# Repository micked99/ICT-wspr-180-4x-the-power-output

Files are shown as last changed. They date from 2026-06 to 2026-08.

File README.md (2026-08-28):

Utilize the clock inverter of the Si5351 and tx the signal 180 deg out of phase on the two dipole halfs increasing the power output in theory up to 4 times, in real life we will likley see a 3x increase.

Quick messure of powerdemands - about 32mA at tx at test freq wspr 21Mhz into a dipole

PCB have been altered and the clk1 have been routed to the pcb

My original ict fw works on this pcb as only difference is the extra clk line

All setup is same as this: https://github.com/micked99/ICT-Wspr-complete-setup

This is V2 of the 180° pcb, tested and working

180deg-pcb

pcbs

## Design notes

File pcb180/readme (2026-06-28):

Files to order the pcb including .brd file and the cam files in the .zip

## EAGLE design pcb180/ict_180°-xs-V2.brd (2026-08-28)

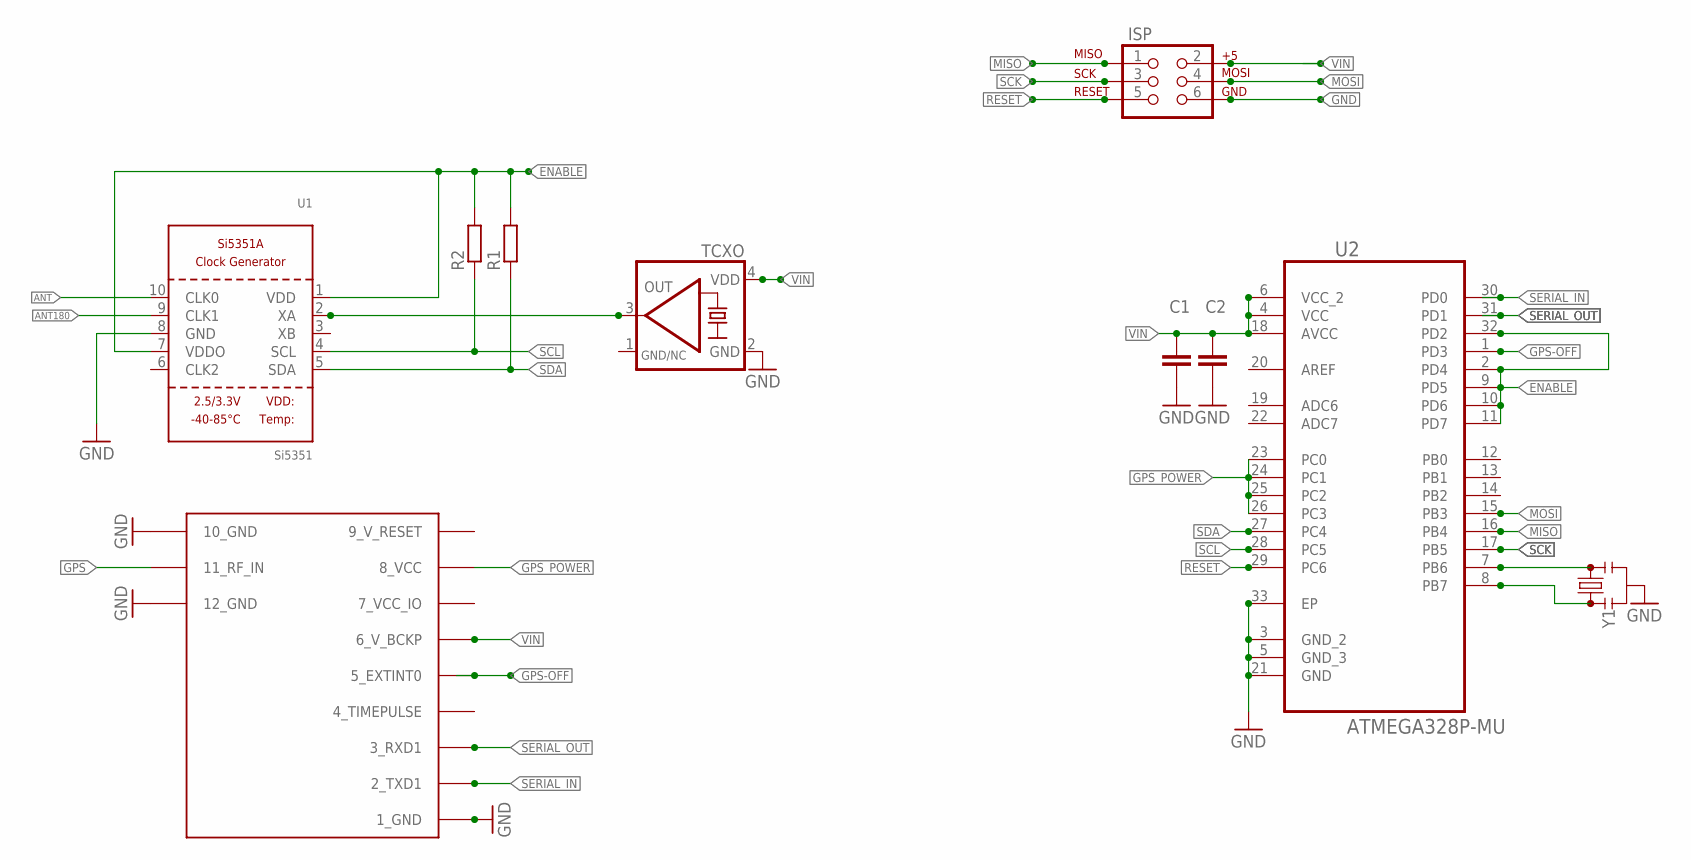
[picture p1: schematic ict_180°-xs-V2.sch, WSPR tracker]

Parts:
C1, C2: C-EUC0603K; C0603K
GPS: UBLOX_MAX
ISP: AVR_SPI_PRG_6PTH; 2X3
R1, R2: R-EU_R0603; R0603
TCXO: KXO-TCXO-CMOS-84; 3.2X2.5_KXO-84-TCXO
U1: Si5351; MSOP10
U2: ATMEGA328P-MU; QFN50P500X500X100-33N
Y1: RESONATORSMD-4.5X2.0; RESONATOR-SMD-4.5X2.0

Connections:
7_VCC_IO: GPS.7_VCC_IO
9_V_RESET: GPS.9_V_RESET
ANT: U1.10 (CLK0)
ANT180: U1.9 (CLK1)
ENABLE: R1.2, R2.2, U1.1 (VDD), U1.7 (VDDO), U2.2 (PD4), U2.9 (PD5), U2.10 (PD6), U2.11 (PD7), U2.32 (PD2)
GND: C1.2, C2.2, GPS.1_GND, GPS.10_GND, GPS.12_GND, ISP.6, TCXO.2 (GND), U1.8 (GND), U2.3 (GND_2), U2.5 (GND_3), U2.21 (GND), U2.33 (EP), Y1.2
GND/NC: TCXO.1 (GND/NC)
GPS: GPS.11_RF_IN
GPS-OFF: GPS.5_EXTINT0, U2.1 (PD3)
GPS_POWER: GPS.8_VCC, U2.23 (PC0), U2.24 (PC1), U2.25 (PC2), U2.26 (PC3)
MISO: ISP.1, U2.16 (PB4)
MOSI: ISP.4, U2.15 (PB3)
unnamed: U2.7 (PB6), Y1.3
unnamed: U2.8 (PB7), Y1.1
unnamed: TCXO.3 (OUT), U1.2 (XA)
RESET: ISP.5, U2.29 (PC6)
SCK: ISP.3, U2.17 (PB5)
SCL: R2.1, U1.4 (SCL), U2.28 (PC5)
SDA: R1.1, U1.5 (SDA), U2.27 (PC4)
SERIAL_IN: GPS.2_TXD1, U2.30 (PD0)
SERIAL_OUT: GPS.3_RXD1, U2.31 (PD1)
VIN: C1.1, C2.1, GPS.6_V_BCKP, ISP.2, TCXO.4 (VDD), U2.4 (VCC), U2.6 (VCC_2), U2.18 (AVCC)

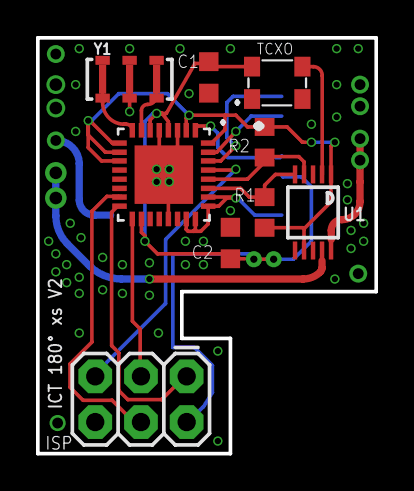
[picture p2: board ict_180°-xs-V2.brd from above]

Board: 2 copper layers, 18.8 x 23.1 mm, 10 parts (1 on the bottom side), 16 nets.

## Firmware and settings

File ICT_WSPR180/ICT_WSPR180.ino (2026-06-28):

//#pragma GCC diagnostic error "-Wconversion"

/*
   HABalloon by KD2NDR, Miami Florida October 25 2018
   Improvements by YO3ICT, Bucharest Romania, April-May 2019 
   Improvements By SA6BSS, Sweden, fall 2020
   You may use and modify the following code to suit
   your needs so long as it remains open source
   and it is for non-commercial use only.
*/

#include <avr/wdt.h>
#include <TimeLib.h>
#include <TinyGPS++.h>
#include <JTEncode.h>
#include <Wire.h>
#include <avr/pgmspace.h>
#include <avr/power.h>

//#define WSPR_FREQ     3570185UL  // <<<<< SET TX FREQUENCY HERE
//#define WSPR_FREQ     7040185UL  // <<<<< SET TX FREQUENCY HERE
//#define WSPR_FREQ     10140285UL // <<<<< SET TX FREQUENCY HERE
//#define WSPR_FREQ     14097190UL // <<<<< SET TX FREQUENCY HERE
//#define WSPR_FREQ     18106200UL  // <<<<< SET TX FREQUENCY HERE
#define WSPR_FREQ     21096190UL // <<<<< SET TX FREQUENCY HERE         
//#define WSPR_FREQ     28126235UL // <<<<< SET TX FREQUENCY HERE
#define ISM_WSPR_FREQ   13555425UL // = 1,500Hz audio on 13.553.900 Mhz // 13555425UL New correct ism freq
#define WSPR_CTC        1334       // WSPR CTC - 2668 @ 4Mhz //1334 @ 2Mhz //667 @ 1Mhz


// Enumerations
enum mode {MODE_WSPR};
TinyGPSPlus gps;
JTEncode jtencode;

// Global variables
unsigned long freq;
const char call[] = "SA7BSS";   // WSPR Standard callsign
char call_telemetry[7];         // WSPR telemetry callsign
char loc_telemetry[5];          // WSPR telemetry locator
char TestGrid[5];               // Testing grid for Geofence
uint8_t dbm, dbm_telemetry;     // Standard WSPR dbm - coarse altitude & WSPR telemetry dbm
char message_jt9[14] = "";      // JT9 Message (13 char limit)
char loc4[5];                   // 4 digit gridsquare locator
byte Hour, Minute, Second;      // Used for timing
long lat, lon, oldlat, oldlon;  // Used for location
uint8_t tx_buffer[255];         // WSPR Tx buffer
uint8_t symbol_count;           // JTencode
uint16_t tone_delay, tone_spacing, CTC; // JTencode
int alt_meters = 0;
int telemetry_set = 0;
int Sats = 0;
int gps_speed = 0;
volatile bool proceed = false;
long lastMillis = 0; 
int pwr_level=79; // Set between 76-79, to slowly increase power to ease load on the solar cells at low solar angles, 76 is really low so use from 77 and up.
int w=1;
bool Outside = true;            // Geofence flag
//GeoFence grids by Matt Downs - 2E1GYP //Airborne transmissions of this sort are not legal over North Korea and Yemen
const char NoTXGrids[] PROGMEM = {"PN31 PN41 PN20 PN30 PN40 PM29 PM39 PM28 PM38 LK16 LK15 LK14 LK13 LK23 LK24 LK25 LK26 LK36 LK35 LK34 LK33 LK44 LK45 LK46 LK47 LK48 LK58 LK57 LK56 LK55"};

#include "TelemFunctions.h"     // Various telemetry functions
#include "Beep.h"               // beeps and CW
#include "Timing-test.h"            // Scheduling, set Timing4.h for testing, it will then tx on first 2 min slot after power on, for flight set Timing.h and it will tx on the nominal 10 min scheduling

// Function Prototype
void wdt_init(void) __attribute__ ((naked, used, section(".init3")));
// Function Implementation
void wdt_init(void)
 {
  MCUSR = 0x00;  //Clear all reset flags
  WDTCSR |= (1 << WDCE) | (1 << WDE);
  WDTCSR = (1 << WDP3) | (1 << WDP0);
  return;
 }

void setup()
 {
  cli(); //Disable global interrupts
  WDTCSR |= (1 << WDCE) | (1 << WDE);
  WDTCSR = (0 << WDIE) | (1 << WDE) | (1 << WDP3) | (1 << WDP0);  // First enable the watchdog timer
  sei(); //Enable global interrupts

  clock_prescale_set(clock_div_2);
  //clock_prescale_set(clock_div_4);

  pinMode(2, OUTPUT);  // Si5351 off
  pinMode(4, OUTPUT);
  pinMode(5, OUTPUT);
  pinMode(6, OUTPUT);
  pinMode(7, OUTPUT);
  
  cw_s(); cw_a(); cw_6(); cw_b(); cw_s(); cw_s(); // Set callsign of the CW id at startup
  
  delay(80);
  pinMode(A0, OUTPUT); // GPS VCC on
  pinMode(A1, OUTPUT);
  pinMode(A2, OUTPUT);
  pinMode(A3, OUTPUT);
  digitalWrite(A0, HIGH);
  digitalWrite(A1, HIGH);
  digitalWrite(A2, HIGH);
  digitalWrite(A3, HIGH);
  delay(1500);
  Serial.begin(9600);

  //delay(2500); Serial.write("$PMTK886,3*2B\r\n");   //set balloon mode for QUECTEL L70 GPS module
  delay(2500); Serial.write("$PCAS04,1*18\r\n");      //GPS only ATGM336
  //delay(2500); Serial.write("$PCAS04,2*1B\r\n");    //BD  only ATGM336
  //delay(2500); Serial.write("$PCAS04,7*1E\r\n");    //All ATGM336 
  //delay(2500); Serial.print("$PSIMNAV,W,3*3A\r\n"); //Sets Balloon mode of L70
  //delay(2500); Serial.write("$PMTK127*36\r\n");     //Erase EPO data stored in the flash memory - L70
  //delay(2500); Serial.write("$PMTK120*31\r\n");     //Erase aiding data stored in the flash memory - L70
  //delay(2500); Serial.write("$PMTK104*37\r\n");     //resets the GNSS module to the factory default - L70

  wdt_reset();
 }

ISR(TIMER1_COMPA_vect) // Interrupt to drive the TX timing
 {  proceed = true; }

void loop()
 {
  wdt_reset();
  while (Serial.available() > 0)
  if (gps.encode(Serial.read()))            // GPS related functions need to be in here to work with tinyGPS Plus library
  {
    wdt_reset();
  }
  if (gps.location.isValid())
  {
  if (timeStatus() == timeNotSet)           // Only sets time if already not done previously
  {
    setGPStime();                           // Sets system time to GPS UTC time for sync
  }
    TXtiming();                             // Process timing
  }
  }

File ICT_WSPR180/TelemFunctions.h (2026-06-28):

/*
   Telemetry functions  // 180 deg push-pull CLK0/CLK1
*/

void setGPStime() // Sets the system time from the GPS
 {
  if (gps.time.isValid())
 {
    Hour = gps.time.hour();
    Minute = gps.time.minute();
    Second = gps.time.second();
    setTime(Hour, Minute, Second, 1, 1, 2000); // (hr,min,sec,day,month,yr)
 }
 }

void locjt9() // Calculates full locator from GPS
 {
  lon = (gps.location.lng() * 100000) + 18000000L;
  lat = (gps.location.lat() * 100000) +  9000000L;
  char MH[13] = {'A', 'A', 'A', 'A', 'A', 'A', '-', 'A', 'A', 'A', 'A', 'A', 'A'};
  MH[5] += lat % 25;
  unsigned long q = lat / 25;
  MH[4] += q % 25;
  q = q / 25;
  MH[3] += q % 25;
  q = q / 25;
  MH[2] += q % 25;
  q = q / 25;
  MH[1] += q % 25;
  MH[0] += q / 25;
  MH[12] += lon % 25;
  q = lon / 25;
  MH[11] += q % 25;
  q = q / 25;
  MH[10] += q % 25;
  q = q / 25;
  MH[9] += q % 25;
  q = q / 25;
  MH[8] += q % 25;
  MH[7] += q / 25;
  String locjt9_txt = "";
  int i = 0;
  while (i < 13) {
  locjt9_txt += MH[i];
  i++;
 }
  locjt9_txt.toCharArray(message_jt9, 14);
 }

void loc4calc() // Determine the locator from the GPS data
 {
  lon = (gps.location.lng() * 100000) + 18000000L;
  lat = (gps.location.lat() * 100000) +  9000000L;
  char MH[4] = {'A', 'A', '0', '0'};
  MH[0] +=  lon / 2000000;
  MH[1] +=  lat / 1000000;
  MH[2] += (lon % 2000000) / 200000;
  MH[3] += (lat % 1000000) / 100000;
  String loc4_txt = "";
  int i = 0;
  while (i < 4) {
    loc4_txt += MH[i];
    i++;
 }
  loc4_txt.toCharArray(loc4, 5);
 }

void call_telem() // Determine the telemetry callsign
 {
  alt_meters = gps.altitude.meters();
  char MH[2] = {'A', 'A'};
  MH[0] += ((lon % 200000) / 8333);
  MH[1] += ((lat % 100000) / 4166);
  // Telemetry channel 0-19 - 00 01 02 - 08 09 - Q0 Q1 Q2 - Q8 Q9
  call_telemetry[0] = '0';  // set 0 or Q
  call_telemetry[2] = '8';  // set 0 to 9
  int a = MH[0] - 'A';
  int b = MH[1] - 'A';
  int c = a * 24 + b;
  int d = int(alt_meters / 20);
  long e = (long)(1068L * c + d);
  long f = float(e / 17576L);
  if (f < 10)
  call_telemetry[1] = f + '0';
  else
  call_telemetry[1] = f - 10 + 'A';
  long g = e - f * 17576L;
  int h = int(g / 676);
  call_telemetry[3] = h + 'A';
  long i = g - h * 676L;
  int j = int(i / 26);
  call_telemetry[4] = j + 'A';
  long k = i - j * 26L;
  int l = int(k / 1);
  call_telemetry[5] = l + 'A';
 }

void loc_dbm_telem() // Determine the locator and dBm value for the telemetry transmission
 {
  Sats =  gps.satellites.value();
  gps_speed = gps.speed.knots();
  int wADC = 0;
  int temp = 0;
  float volt = 0;
  int sensorVolt = 0;
  ADMUX = (_BV(REFS1) | _BV(REFS0) | _BV(MUX3));
  ADCSRA |= _BV(ADEN);
  delay(20);
  for (int i=0;i<5;i++)
 {
  ADCSRA |= _BV(ADSC);
  while (bit_is_set(ADCSRA, ADSC));
  wADC = wADC + ADCW;
  delay(20);
 }
  wADC = wADC / 5;
  temp = (wADC - 305.11 ) / 1.15;
  delay(20);
  analogReference(INTERNAL);
  for (int i=0;i<5;i++)
 {
  sensorVolt = sensorVolt + analogRead(0); //analogRead(0) for the old boards
 }
  sensorVolt = sensorVolt / 5;   // mark out for fixed voltage
  volt = sensorVolt * 1.1f;      // mark out for fixed voltage
  volt = volt / 1023.0f;         // mark out for fixed voltage
  volt = volt * 4.18f;           // mark out for fixed voltage
 // volt = 3.54;                     // Remove if sensor voltage is used
  if (volt < 3.0) volt = 3.0;    // mark out for fixed voltage
  if (volt > 4.95) volt = 4.95;  // mark out for fixed voltage
  if (temp < -49) temp = -49;
  if (temp > 39) temp = 39;
  int GPS = 0;
  if ((lon != oldlon) || (lat != oldlat))
  GPS = 1;
  else
  GPS = 0;
  oldlon = lon;
  oldlat = lat;
  if (Sats < 5) Sats = 0; else Sats = 1;
  int temp_raw = (int)(1024L * (temp * 0.01 + 2.73)) / 5;
  temp_raw = (int)(temp_raw - 457) / 2;
  float batt_raw = (int)(1024L * volt) / 5;
  batt_raw = (batt_raw - 614) / 10;
  float round_number = round(batt_raw);
  if (round_number > batt_raw) round_number = round_number - 1;
  batt_raw = (int)round_number;
  long x = (temp_raw * 40L ) + batt_raw;
  long y = (x * 42L) + (int)gps_speed / 2;
  long z = (y * 2L) + (int)GPS;
  long xy = (z * 2L) + (int)Sats;
  long a = (int)(xy / 34200L);
  loc_telemetry[0] = a + 'A';
  long b = xy - (34200L * a);
  long c = (int)(b / 1900L);
  loc_telemetry[1] = c + 'A';
  long d = b - (1900L * c);
  long e = (int)(d / 190L);
  loc_telemetry[2] = e + '0';
  long f = d - (190L * e);
  long g = (int) (f / 19L);
  loc_telemetry[3] = g + '0';
  dbm_telemetry = f - (g * 19L);
  if (dbm_telemetry == 0) dbm_telemetry = 0;
  else if (dbm_telemetry == 1) dbm_telemetry = 3;
  else if (dbm_telemetry == 2) dbm_telemetry = 7;
  else if (dbm_telemetry == 3) dbm_telemetry = 10;
  else if (dbm_telemetry == 4) dbm_telemetry = 13;
  else if (dbm_telemetry == 5) dbm_telemetry = 17;
  else if (dbm_telemetry == 6) dbm_telemetry = 20;
  else if (dbm_telemetry == 7) dbm_telemetry = 23;
  else if (dbm_telemetry == 8) dbm_telemetry = 27;
  else if (dbm_telemetry == 9) dbm_telemetry = 30;
  else if (dbm_telemetry == 10) dbm_telemetry = 33;
  else if (dbm_telemetry == 11) dbm_telemetry = 37;
  else if (dbm_telemetry == 12) dbm_telemetry = 40;
  else if (dbm_telemetry == 13) dbm_telemetry = 43;
  else if (dbm_telemetry == 14) dbm_telemetry = 47;
  else if (dbm_telemetry == 15) dbm_telemetry = 50;
  else if (dbm_telemetry == 16) dbm_telemetry = 53;
  else if (dbm_telemetry == 17) dbm_telemetry = 57;
  else if (dbm_telemetry == 18) dbm_telemetry = 60;
 }
 
#define WSPR_TONE_SPACING  146     // ~1.46 Hz
#define WSPR_DELAY         683     // Delay value for WSPR

void geofence_check()
 {
  Outside = true;
  for (unsigned int GridLoop = 0; GridLoop < sizeof(NoTXGrids); GridLoop = GridLoop + 5)
 {
  for (int CharLoop = 0; CharLoop < 4; CharLoop++)
 {
      TestGrid[CharLoop] = pgm_read_byte_near (NoTXGrids + CharLoop + GridLoop);
 }
  if ((loc4[0] == TestGrid[0]) && (loc4[1] == TestGrid[1]) && (loc4[2] == TestGrid[2]) && (loc4[3] == TestGrid[3])) {
      Outside = false;
      break;
 }
 }
 }

void dbm_alt() // Coarse altitude for WSPR standard message dBm value
 {
  alt_meters = gps.altitude.meters();
  if (alt_meters >= 15000) dbm = 0;
  else if (alt_meters >= 14600) dbm = 3;
  else if (alt_meters >= 14200) dbm = 7;
  else if (alt_meters >= 13800) dbm = 10;
  else if (alt_meters >= 13400) dbm = 13;
  else if (alt_meters >= 13000) dbm = 17;
  else if (alt_meters >= 12600) dbm = 20;
  else if (alt_meters >= 12200) dbm = 23;
  else if (alt_meters >= 11800) dbm = 27;
  else if (alt_meters >= 11400) dbm = 30;
  else if (alt_meters >= 11000) dbm = 33;
  else if (alt_meters >= 10600) dbm = 37;
  else if (alt_meters >= 10200) dbm = 40;
  else if (alt_meters >= 9800) dbm = 43;
  else if (alt_meters >= 8000) dbm = 47;
  else if (alt_meters >= 6000) dbm = 50;
  else if (alt_meters >= 3000) dbm = 53;
  else if (alt_meters >= 1000) dbm = 57;
  else dbm = 60;
 }
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

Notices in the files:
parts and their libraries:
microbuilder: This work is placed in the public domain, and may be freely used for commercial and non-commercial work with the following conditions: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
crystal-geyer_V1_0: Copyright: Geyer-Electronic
